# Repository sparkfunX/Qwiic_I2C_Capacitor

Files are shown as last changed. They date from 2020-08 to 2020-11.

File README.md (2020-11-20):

SparkFun Qwiic Digital Capacitor
=============================

SparkFun Qwiic Digital Capacitor - NCD2400M

[*SparkFun Qwiic Digital Capacitor NCD2400M (SPX- 17182)*](https://www.sparkfun.com/products/17182) 

Ever need to fine tune an oscillator circuit or RF filter? It can be tricky and repetitive switching out capacitors on a PCB. The Qwiic Digital Capacitor, complete with the NCD2400M IC, can be a great solution. Solder the nibs onto any 0603 or 0402 footprint, plug in a Qwiic cable and RedBoard, and change the capacitance in code.

Repository Contents
-------------------

* **/Documents** - Datasheet for the NCD2400M IC.
* **/Hardware** - Eagle design files (.brd, .sch).
* **/Production** - Production panel files (.brd).

Documentation
-------------
* **[Arduino Library](https://github.com/sparkfun/SparkFun_Qwiic_Digital_Capacitor_Arduino_Library)** - Arduino library for the SparkFun Qwiic Digital Capacitor - NCD2400M.

License Information
-------------------

This product is _**open source**_!

Please review the LICENSE.md file for license information.

If you have any questions or concerns regarding our licensing, please contact technical support on our [SparkFun Forum](https://www.sparkfun.com/viewforum.php?f=152).

Distributed as-is; no warranty is given.

- Your friends at SparkFun

_<COLLABORATION CREDIT>_

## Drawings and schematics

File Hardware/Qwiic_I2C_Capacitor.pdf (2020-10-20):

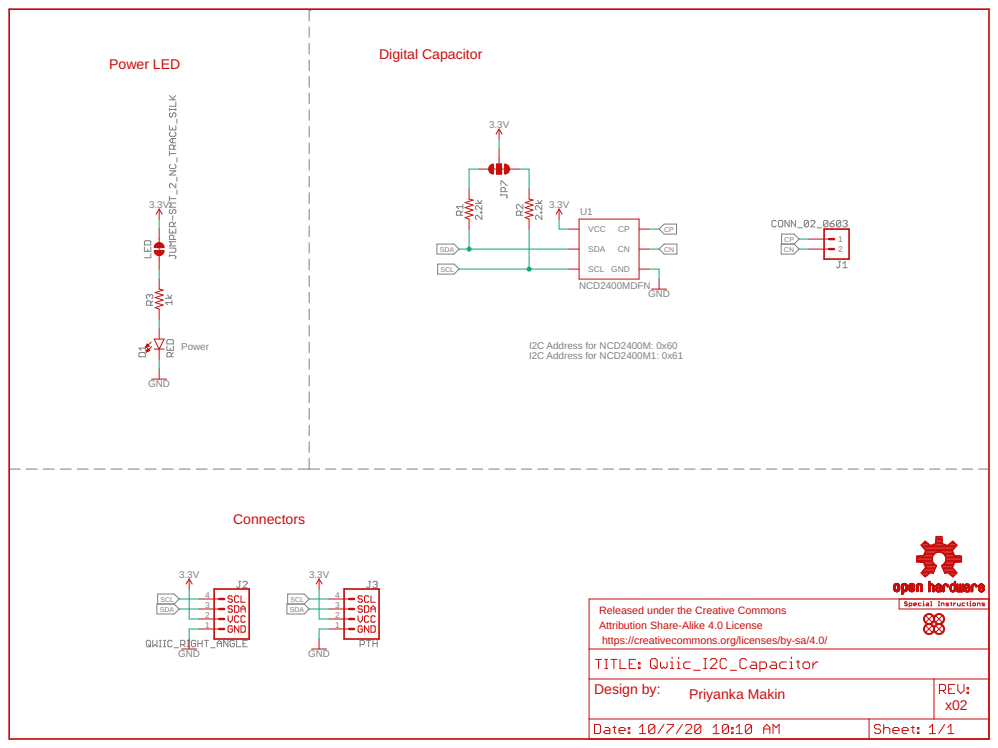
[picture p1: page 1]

Released under the Creative Commons Attribution Share-Alike 4.0 License

https://creativecommons.org/licenses/by-sa/4.0/

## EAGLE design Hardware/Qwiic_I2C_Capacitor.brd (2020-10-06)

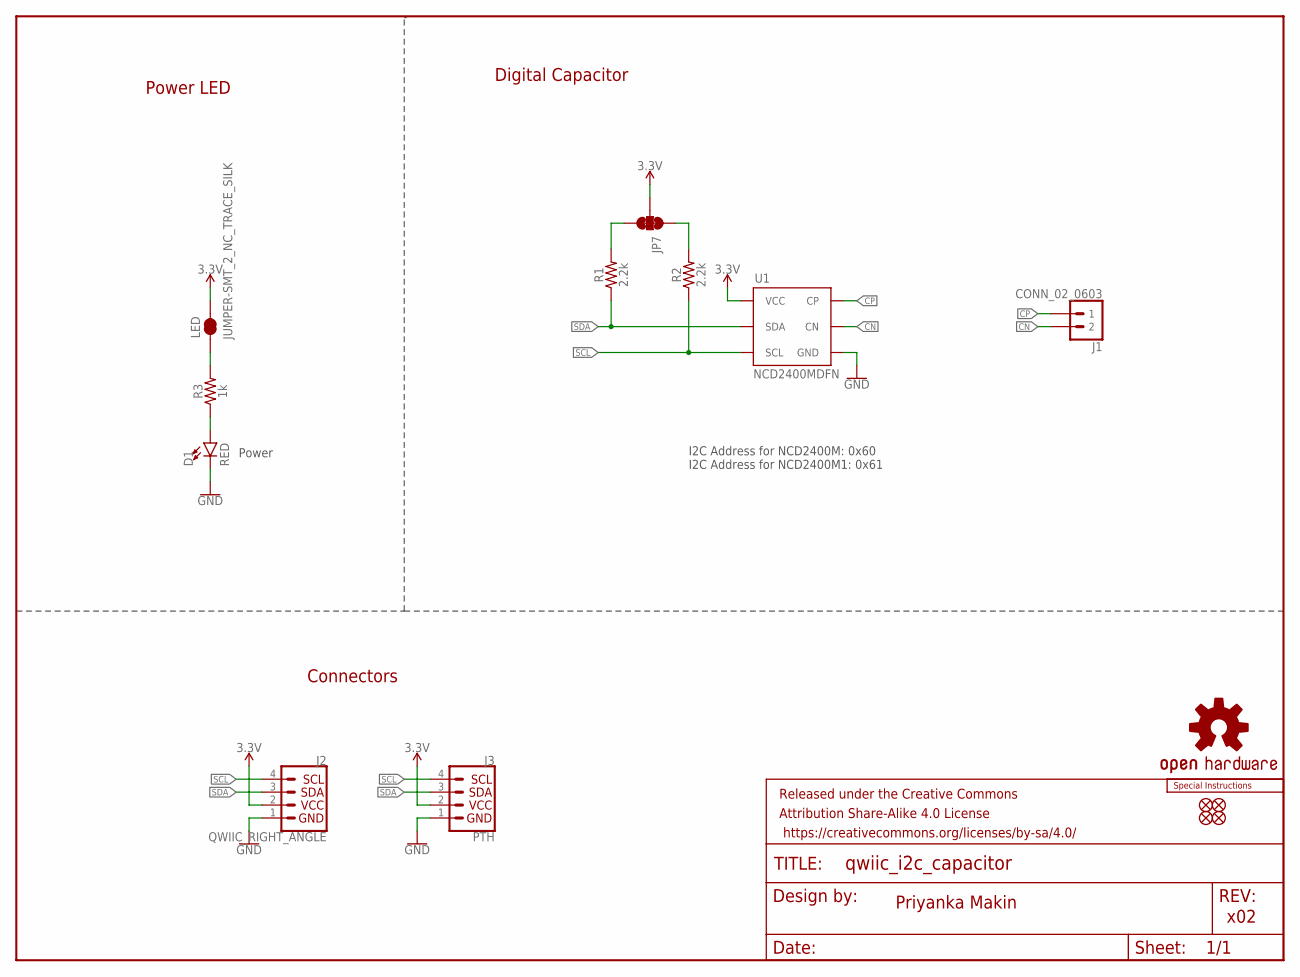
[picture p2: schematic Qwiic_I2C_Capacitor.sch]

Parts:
D1: RED; LED-0603
FRAME1: FRAME-LETTER; CREATIVE_COMMONS
J1: CONN_02_0603; 0603_CASTELLATED
J2: QWIIC_RIGHT_ANGLE; JST04_1MM_RA
J3: PTH; 1X04_NO_SILK
JP1, JP2, JP5, JP6: FIDUCIAL0.2MM; FIDUCIAL-0.2MM
JP7: JUMPER-SMT_3_2-NC_TRACE_SILK; SMT-JUMPER_3_2-NC_TRACE_SILK
LED: JUMPER-SMT_2_NC_TRACE_SILK; SMT-JUMPER_2_NC_TRACE_SILK
LOGO1: OSHW-LOGOMINI; OSHW-LOGO-MINI
LOGO2: SPECIAL_INSTRUCTIONS-ORDERING; ORDERING_INSTRUCTIONS
R1, R2: 2.2k; 0603
R3: 1k; 0603
U1: NCD2400MDFN; DFN6

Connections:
3.3V: J2.2, J3.2 (VCC), JP7.2, LED.2, U1.4 (VCC)
CN: J1.2, U1.3 (CN)
CP: J1.1, U1.2 (CP)
GND: D1.C, J2.1, J3.1 (GND), U1.5 (GND)
unnamed: JP7.3, R1.2
unnamed: JP7.1, R2.2
unnamed: D1.A, R3.1
unnamed: LED.1, R3.2
SCL: J2.4, J3.4 (SCL), R2.1, U1.6 (SCL)
SDA: J2.3, J3.3 (SDA), R1.1, U1.1 (SDA)

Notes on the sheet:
x02
Power
Connectors
Priyanka Makin
I2C Address for NCD2400M: 0x60 I2C Address for NCD2400M1: 0x61
Digital Capacitor
Power LED

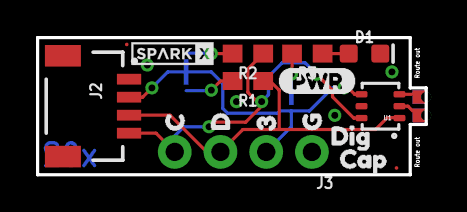
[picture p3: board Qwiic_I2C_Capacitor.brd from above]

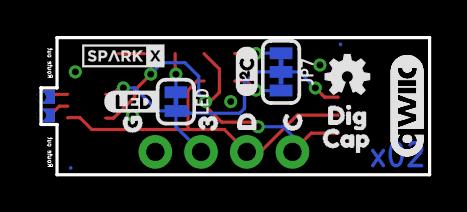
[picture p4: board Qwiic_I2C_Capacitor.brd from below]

Board: 2 copper layers, 21.6 x 7.6 mm, 36 parts (16 on the bottom side), 10 nets.

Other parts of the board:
U$1: PWR2
U$3, U$7: 32
U$4, U$8: C0
U$5, U$13: D1
U$6, U$14: G3
U$9: I_SUPER2_C-()-03
U$11, U$18: CAP1
U$12, U$16: SPARKX-TINY
U$15: LED0
U$20, U$21: QWIIC_COPYRIGHT_SMALL
U$22, U$23: DIG0

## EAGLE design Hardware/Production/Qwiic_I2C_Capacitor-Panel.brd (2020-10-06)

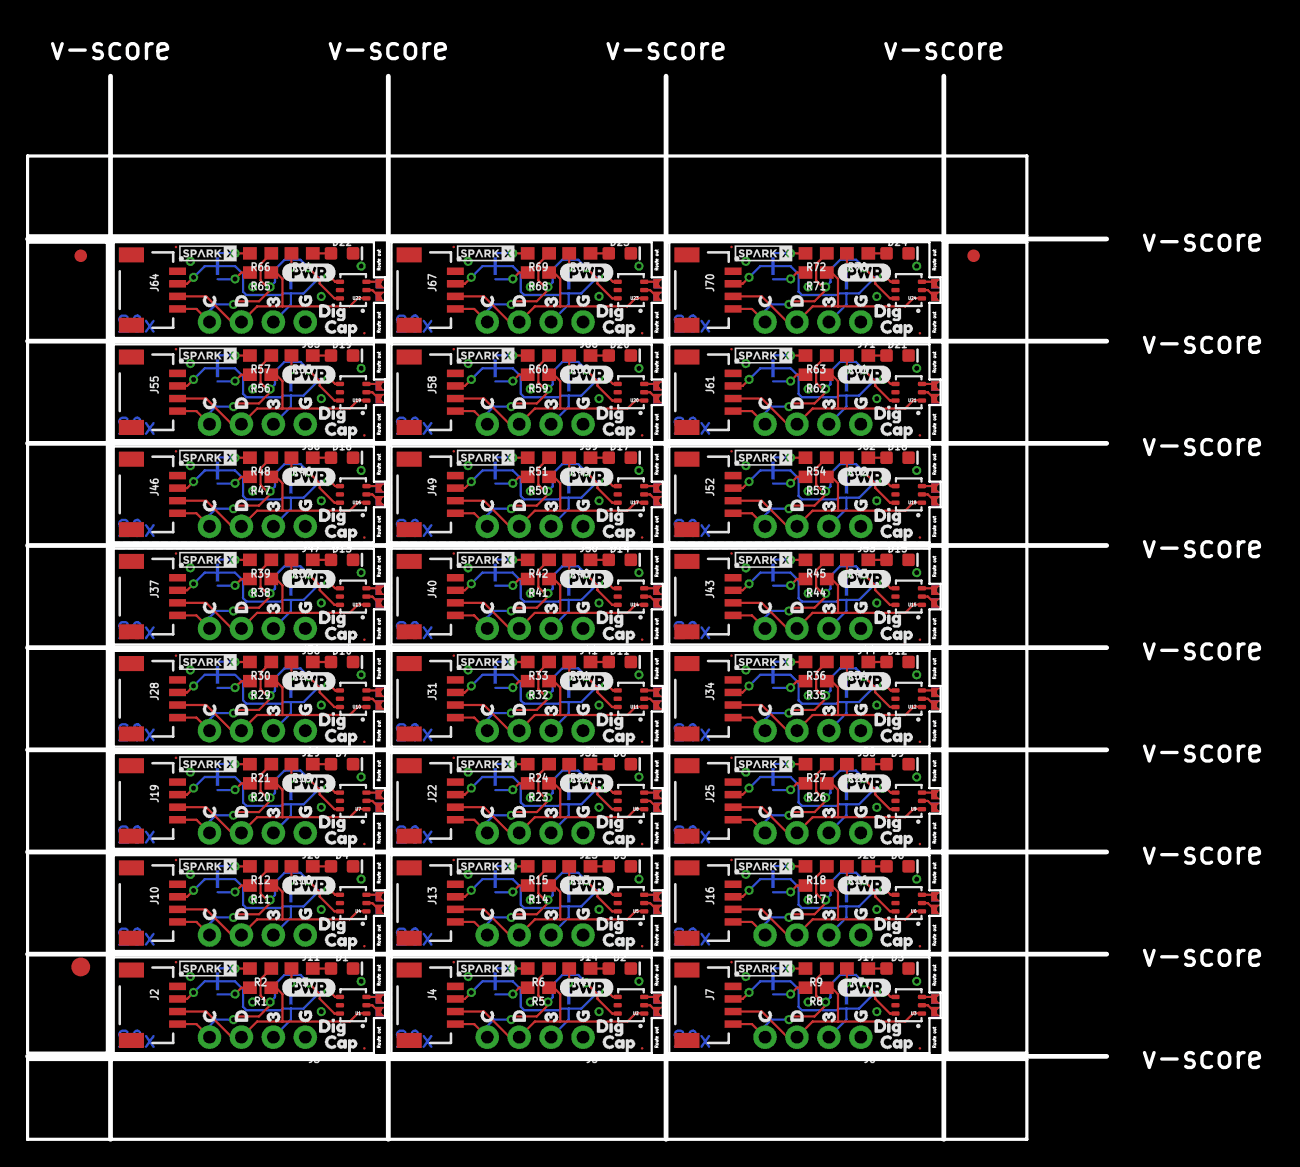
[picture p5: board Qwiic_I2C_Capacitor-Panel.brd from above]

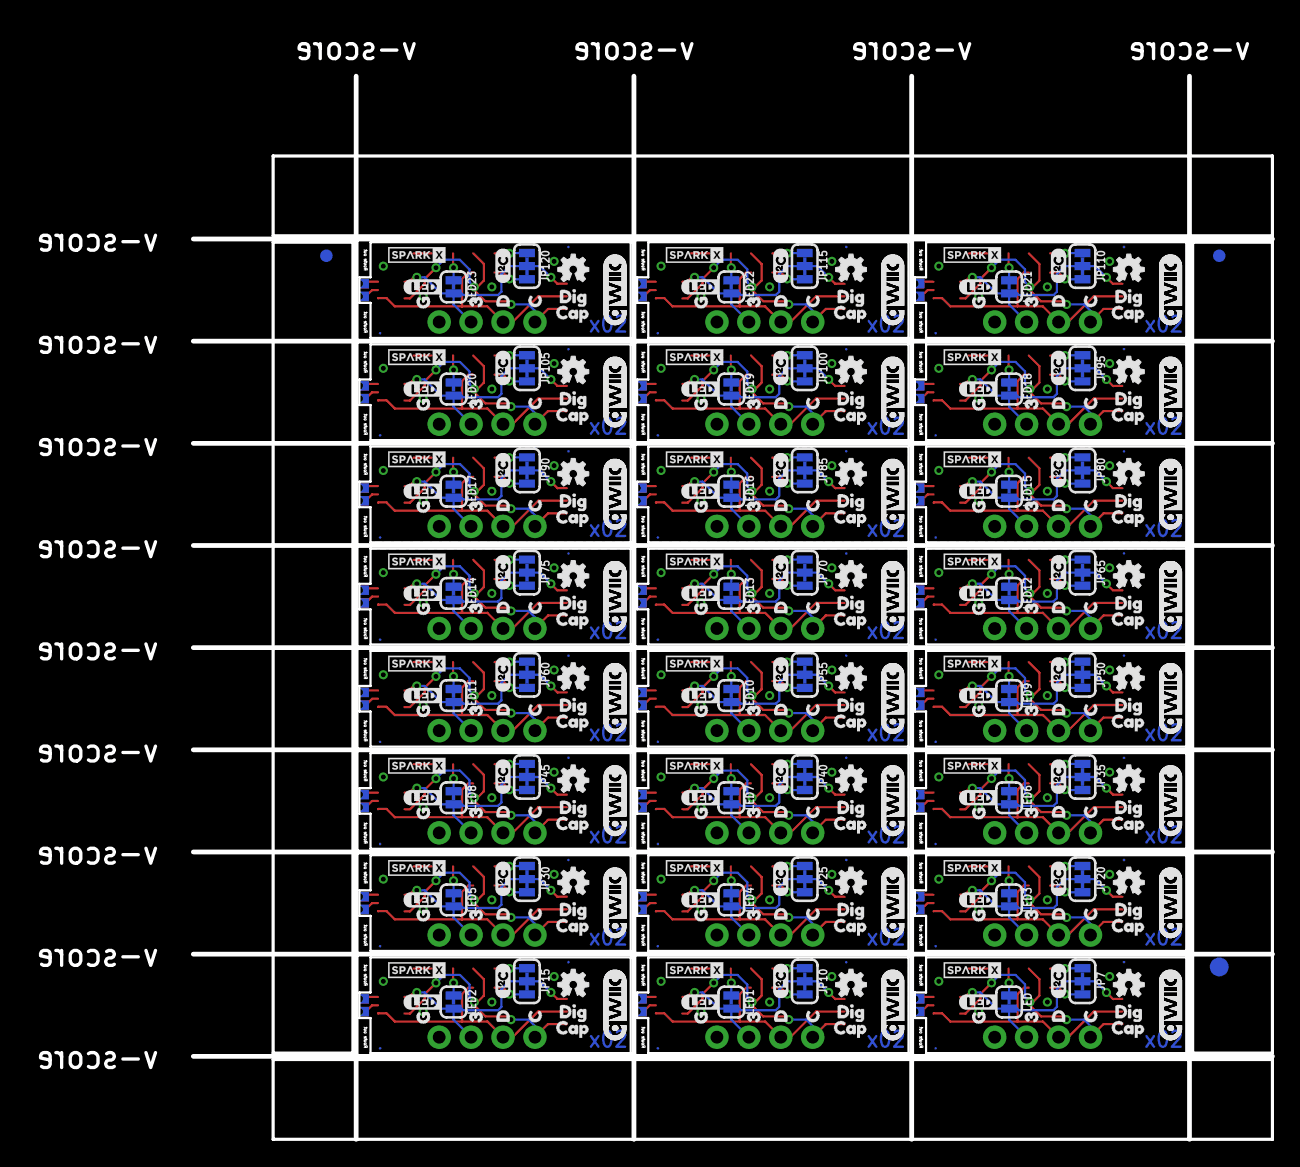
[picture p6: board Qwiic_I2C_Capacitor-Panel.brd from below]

Board: 2 copper layers, 85.9 x 84.6 mm, 822 parts (387 on the bottom side), 240 nets.

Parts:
D1, D2, D3, D4, D5, D6, D7, D8, D9, D10, D11, D12, D13, D14, D15, D16, D17, D18, D19, D20, D21, D22, D23, D24: RED; LED-0603
E$1, E$2, E$3, E$4: FIDUCIAL-1X2
E$5, E$6: FIDUCIAL-1.5X3
J1, J6, J9, J12, J15, J18, J21, J24, J27, J30, J33, J36, J39, J42, J45, J48, J51, J54, J57, J60, J63, J66, J69, J72: CONN_02_0603; 0603_CASTELLATED
J2, J4, J7, J10, J13, J16, J19, J22, J25, J28, J31, J34, J37, J40, J43, J46, J49, J52, J55, J58, J61, J64, J67, J70: QWIIC_RIGHT_ANGLE; JST04_1MM_RA
J3, J5, J8, J11, J14, J17, J20, J23, J26, J29, J32, J35, J38, J41, J44, J47, J50, J53, J56, J59, J62, J65, J68, J71: PTH; 1X04_NO_SILK
JP1, JP2, JP3, JP4, JP5, JP6, JP8, JP9, JP11, JP12, JP13, JP14, JP16, JP17, JP18, JP19, JP21, JP22, JP23, JP24, JP26, JP27, JP28, JP29, JP31, JP32, JP33, JP34, JP36, JP37, JP38, JP39, JP41, JP42, JP43, JP44, JP46, JP47, JP48, JP49, JP51, JP52, JP53, JP54, JP56, JP57, JP58, JP59, JP61, JP62, JP63, JP64, JP66, JP67, JP68, JP69, JP71, JP72, JP73, JP74, JP76, JP77, JP78, JP79, JP81, JP82, JP83, JP84, JP86, JP87, JP88, JP89, JP91, JP92, JP93, JP94, JP96, JP97, JP98, JP99, JP101, JP102, JP103, JP104, JP106, JP107, JP108, JP109, JP111, JP112, JP113, JP114, JP116, JP117, JP118, JP119: FIDUCIAL0.2MM; FIDUCIAL-0.2MM
JP7, JP10, JP15, JP20, JP25, JP30, JP35, JP40, JP45, JP50, JP55, JP60, JP65, JP70, JP75, JP80, JP85, JP90, JP95, JP100, JP105, JP110, JP115, JP120: JUMPER-SMT_3_2-NC_TRACE_SILK; SMT-JUMPER_3_2-NC_TRACE_SILK
LED, LED1, LED2, LED3, LED4, LED5, LED6, LED7, LED8, LED9, LED10, LED11, LED12, LED13, LED14, LED15, LED16, LED17, LED18, LED19, LED20, LED21, LED22, LED23: JUMPER-SMT_2_NC_TRACE_SILK; SMT-JUMPER_2_NC_TRACE_SILK
LOGO1, LOGO2, LOGO3, LOGO4, LOGO5, LOGO6, LOGO7, LOGO8, LOGO9, LOGO10, LOGO11, LOGO12, LOGO13, LOGO14, LOGO15, LOGO16, LOGO17, LOGO18, LOGO19, LOGO20, LOGO21, LOGO22, LOGO23, LOGO24: OSHW-LOGOMINI; OSHW-LOGO-MINI
R1, R2, R5, R6, R8, R9, R11, R12, R14, R15, R17, R18, R20, R21, R23, R24, R26, R27, R29, R30, R32, R33, R35, R36, R38, R39, R41, R42, R44, R45, R47, R48, R50, R51, R53, R54, R56, R57, R59, R60, R62, R63, R65, R66, R68, R69, R71, R72: 2.2k; 0603
R3, R4, R7, R10, R13, R16, R19, R22, R25, R28, R31, R34, R37, R40, R43, R46, R49, R52, R55, R58, R61, R64, R67, R70: 1k; 0603
U1, U2, U3, U4, U5, U6, U7, U8, U9, U10, U11, U12, U13, U14, U15, U16, U17, U18, U19, U20, U21, U22, U23, U24: NCD2400MDFN; DFN6
U$1, U$38, U$57, U$76, U$95, U$114, U$133, U$152, U$171, U$190, U$209, U$228, U$247, U$266, U$285, U$304, U$323, U$342, U$361, U$380, U$399, U$418, U$437, U$456: PWR2
U$2, U$9, U$39, U$58, U$77, U$96, U$115, U$134, U$153, U$172, U$191, U$210, U$229, U$248, U$267, U$286, U$305, U$324, U$343, U$362, U$381, U$400, U$419, U$438: I_SUPER2_C-()-03
U$3, U$7, U$10, U$25, U$40, U$44, U$59, U$63, U$78, U$82, U$97, U$101, U$116, U$120, U$135, U$139, U$154, U$158, U$173, U$177, U$192, U$196, U$211, U$215, U$230, U$234, U$249, U$253, U$268, U$272, U$287, U$291, U$306, U$310, U$325, U$329, U$344, U$348, U$363, U$367, U$382, U$386, U$401, U$405, U$420, U$424, U$439, U$443: 32
U$4, U$8, U$17, U$26, U$41, U$45, U$60, U$64, U$79, U$83, U$98, U$102, U$117, U$121, U$136, U$140, U$155, U$159, U$174, U$178, U$193, U$197, U$212, U$216, U$231, U$235, U$250, U$254, U$269, U$273, U$288, U$292, U$307, U$311, U$326, U$330, U$345, U$349, U$364, U$368, U$383, U$387, U$402, U$406, U$421, U$425, U$440, U$444: C0
U$5, U$13, U$19, U$27, U$42, U$46, U$61, U$65, U$80, U$84, U$99, U$103, U$118, U$122, U$137, U$141, U$156, U$160, U$175, U$179, U$194, U$198, U$213, U$217, U$232, U$236, U$251, U$255, U$270, U$274, U$289, U$293, U$308, U$312, U$327, U$331, U$346, U$350, U$365, U$369, U$384, U$388, U$403, U$407, U$422, U$426, U$441, U$445: D1
U$6, U$14, U$24, U$28, U$43, U$47, U$62, U$66, U$81, U$85, U$100, U$104, U$119, U$123, U$138, U$142, U$157, U$161, U$176, U$180, U$195, U$199, U$214, U$218, U$233, U$237, U$252, U$256, U$271, U$275, U$290, U$294, U$309, U$313, U$328, U$332, U$347, U$351, U$366, U$370, U$385, U$389, U$404, U$408, U$423, U$427, U$442, U$446: G3
U$11, U$18, U$34, U$35, U$53, U$54, U$72, U$73, U$91, U$92, U$110, U$111, U$129, U$130, U$148, U$149, U$167, U$168, U$186, U$187, U$205, U$206, U$224, U$225, U$243, U$244, U$262, U$263, U$281, U$282, U$300, U$301, U$319, U$320, U$338, U$339, U$357, U$358, U$376, U$377, U$395, U$396, U$414, U$415, U$433, U$434, U$452, U$453: CAP1
U$12, U$16, U$30, U$31, U$49, U$50, U$68, U$69, U$87, U$88, U$106, U$107, U$125, U$126, U$144, U$145, U$163, U$164, U$182, U$183, U$201, U$202, U$220, U$221, U$239, U$240, U$258, U$259, U$277, U$278, U$296, U$297, U$315, U$316, U$334, U$335, U$353, U$354, U$372, U$373, U$391, U$392, U$410, U$411, U$429, U$430, U$448, U$449: SPARKX-TINY
U$15, U$29, U$48, U$67, U$86, U$105, U$124, U$143, U$162, U$181, U$200, U$219, U$238, U$257, U$276, U$295, U$314, U$333, U$352, U$371, U$390, U$409, U$428, U$447: LED0
U$20, U$21, U$32, U$33, U$51, U$52, U$70, U$71, U$89, U$90, U$108, U$109, U$127, U$128, U$146, U$147, U$165, U$166, U$184, U$185, U$203, U$204, U$222, U$223, U$241, U$242, U$260, U$261, U$279, U$280, U$298, U$299, U$317, U$318, U$336, U$337, U$355, U$356, U$374, U$375, U$393, U$394, U$412, U$413, U$431, U$432, U$450, U$451: QWIIC_COPYRIGHT_SMALL
U$22, U$23, U$36, U$37, U$55, U$56, U$74, U$75, U$93, U$94, U$112, U$113, U$131, U$132, U$150, U$151, U$169, U$170, U$188, U$189, U$207, U$208, U$226, U$227, U$245, U$246, U$264, U$265, U$283, U$284, U$302, U$303, U$321, U$322, U$340, U$341, U$359, U$360, U$378, U$379, U$397, U$398, U$416, U$417, U$435, U$436, U$454, U$455: DIG0

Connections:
3.3V: J2.2, J3.2, JP7.2, LED.2, U1.4
3.3V1: J4.2, J5.2, JP10.2, LED1.2, U2.4
3.3V2: J7.2, J8.2, JP15.2, LED2.2, U3.4
3.3V3: J10.2, J11.2, JP20.2, LED3.2, U4.4
3.3V4: J13.2, J14.2, JP25.2, LED4.2, U5.4
3.3V5: J16.2, J17.2, JP30.2, LED5.2, U6.4
3.3V6: J19.2, J20.2, JP35.2, LED6.2, U7.4
3.3V7: J22.2, J23.2, JP40.2, LED7.2, U8.4
3.3V8: J25.2, J26.2, JP45.2, LED8.2, U9.4
3.3V9: J28.2, J29.2, JP50.2, LED9.2, U10.4
3.3V10: J31.2, J32.2, JP55.2, LED10.2, U11.4
3.3V11: J34.2, J35.2, JP60.2, LED11.2, U12.4
3.3V12: J37.2, J38.2, JP65.2, LED12.2, U13.4
3.3V13: J40.2, J41.2, JP70.2, LED13.2, U14.4
3.3V14: J43.2, J44.2, JP75.2, LED14.2, U15.4
3.3V15: J46.2, J47.2, JP80.2, LED15.2, U16.4
3.3V16: J49.2, J50.2, JP85.2, LED16.2, U17.4
3.3V17: J52.2, J53.2, JP90.2, LED17.2, U18.4
3.3V18: J55.2, J56.2, JP95.2, LED18.2, U19.4
3.3V19: J58.2, J59.2, JP100.2, LED19.2, U20.4
3.3V20: J61.2, J62.2, JP105.2, LED20.2, U21.4
3.3V21: J64.2, J65.2, JP110.2, LED21.2, U22.4
3.3V22: J67.2, J68.2, JP115.2, LED22.2, U23.4
3.3V23: J70.2, J71.2, JP120.2, LED23.2, U24.4
CN: J1.2, U1.3
CN1: J6.2, U2.3
CN2: J9.2, U3.3
CN3: J12.2, U4.3
CN4: J15.2, U5.3
CN5: J18.2, U6.3
CN6: J21.2, U7.3
CN7: J24.2, U8.3
CN8: J27.2, U9.3
CN9: J30.2, U10.3
CN10: J33.2, U11.3
CN11: J36.2, U12.3
CN12: J39.2, U13.3
CN13: J42.2, U14.3
CN14: J45.2, U15.3
CN15: J48.2, U16.3
CN16: J51.2, U17.3
CN17: J54.2, U18.3
CN18: J57.2, U19.3
CN19: J60.2, U20.3
CN20: J63.2, U21.3
CN21: J66.2, U22.3
CN22: J69.2, U23.3
CN23: J72.2, U24.3
CP: J1.1, U1.2
CP1: J6.1, U2.2
CP2: J9.1, U3.2
CP3: J12.1, U4.2
CP4: J15.1, U5.2
CP5: J18.1, U6.2
CP6: J21.1, U7.2
CP7: J24.1, U8.2
CP8: J27.1, U9.2
CP9: J30.1, U10.2
CP10: J33.1, U11.2
CP11: J36.1, U12.2
CP12: J39.1, U13.2
CP13: J42.1, U14.2
CP14: J45.1, U15.2
CP15: J48.1, U16.2
CP16: J51.1, U17.2
CP17: J54.1, U18.2
CP18: J57.1, U19.2
CP19: J60.1, U20.2
CP20: J63.1, U21.2
CP21: J66.1, U22.2
CP22: J69.1, U23.2
CP23: J72.1, U24.2
GND: D1.C, J2.1, J3.1, U1.5
GND1: D2.C, J4.1, J5.1, U2.5
GND2: D3.C, J7.1, J8.1, U3.5
GND3: D4.C, J10.1, J11.1, U4.5
GND4: D5.C, J13.1, J14.1, U5.5
GND5: D6.C, J16.1, J17.1, U6.5
GND6: D7.C, J19.1, J20.1, U7.5
GND7: D8.C, J22.1, J23.1, U8.5
GND8: D9.C, J25.1, J26.1, U9.5
GND9: D10.C, J28.1, J29.1, U10.5
GND10: D11.C, J31.1, J32.1, U11.5
GND11: D12.C, J34.1, J35.1, U12.5
GND12: D13.C, J37.1, J38.1, U13.5
GND13: D14.C, J40.1, J41.1, U14.5
GND14: D15.C, J43.1, J44.1, U15.5
GND15: D16.C, J46.1, J47.1, U16.5
GND16: D17.C, J49.1, J50.1, U17.5
GND17: D18.C, J52.1, J53.1, U18.5
GND18: D19.C, J55.1, J56.1, U19.5
GND19: D20.C, J58.1, J59.1, U20.5
GND20: D21.C, J61.1, J62.1, U21.5
GND21: D22.C, J64.1, J65.1, U22.5
GND22: D23.C, J67.1, J68.1, U23.5
GND23: D24.C, J70.1, J71.1, U24.5
unnamed: JP7.3, R1.2
unnamed: JP7.1, R2.2
unnamed: D1.A, R3.1
unnamed: LED.1, R3.2
unnamed: D2.A, R4.1
unnamed: JP10.3, R5.2
unnamed: JP10.1, R6.2
unnamed: LED1.1, R4.2
unnamed: D3.A, R7.1
unnamed: JP15.3, R8.2
unnamed: JP15.1, R9.2
unnamed: LED2.1, R7.2
unnamed: D4.A, R10.1
unnamed: JP20.3, R11.2
unnamed: JP20.1, R12.2
unnamed: LED3.1, R10.2
unnamed: D5.A, R13.1
unnamed: JP25.3, R14.2
unnamed: JP25.1, R15.2
unnamed: LED4.1, R13.2
unnamed: D6.A, R16.1
unnamed: JP30.3, R17.2
unnamed: JP30.1, R18.2
unnamed: LED5.1, R16.2
unnamed: D7.A, R19.1
unnamed: JP35.3, R20.2
unnamed: JP35.1, R21.2
unnamed: LED6.1, R19.2
unnamed: D8.A, R22.1
unnamed: JP40.3, R23.2
unnamed: JP40.1, R24.2
unnamed: LED7.1, R22.2
unnamed: D9.A, R25.1
unnamed: JP45.3, R26.2
unnamed: JP45.1, R27.2
unnamed: LED8.1, R25.2
unnamed: D10.A, R28.1
unnamed: JP50.3, R29.2
unnamed: JP50.1, R30.2
unnamed: LED9.1, R28.2
unnamed: D11.A, R31.1
unnamed: JP55.3, R32.2
unnamed: JP55.1, R33.2
unnamed: LED10.1, R31.2
unnamed: D12.A, R34.1
unnamed: JP60.3, R35.2
unnamed: JP60.1, R36.2
unnamed: LED11.1, R34.2
unnamed: D13.A, R37.1
unnamed: JP65.3, R38.2
unnamed: JP65.1, R39.2
unnamed: LED12.1, R37.2
unnamed: D14.A, R40.1
unnamed: JP70.3, R41.2
unnamed: JP70.1, R42.2
unnamed: LED13.1, R40.2
unnamed: D15.A, R43.1
unnamed: JP75.3, R44.2
unnamed: JP75.1, R45.2
unnamed: LED14.1, R43.2
unnamed: D16.A, R46.1
unnamed: JP80.3, R47.2
unnamed: JP80.1, R48.2
unnamed: LED15.1, R46.2
unnamed: D17.A, R49.1
unnamed: JP85.3, R50.2
unnamed: JP85.1, R51.2
unnamed: LED16.1, R49.2
unnamed: D18.A, R52.1
unnamed: JP90.3, R53.2
unnamed: JP90.1, R54.2
unnamed: LED17.1, R52.2
unnamed: D19.A, R55.1
unnamed: JP95.3, R56.2
unnamed: JP95.1, R57.2
unnamed: LED18.1, R55.2
unnamed: D20.A, R58.1
unnamed: JP100.3, R59.2
unnamed: JP100.1, R60.2
unnamed: LED19.1, R58.2
unnamed: D21.A, R61.1
unnamed: JP105.3, R62.2
unnamed: JP105.1, R63.2
unnamed: LED20.1, R61.2
unnamed: D22.A, R64.1
unnamed: JP110.3, R65.2
unnamed: JP110.1, R66.2
unnamed: LED21.1, R64.2
unnamed: D23.A, R67.1
unnamed: JP115.3, R68.2
unnamed: JP115.1, R69.2
unnamed: LED22.1, R67.2
unnamed: D24.A, R70.1
unnamed: JP120.3, R71.2
unnamed: JP120.1, R72.2
unnamed: LED23.1, R70.2
SCL: J2.4, J3.4, R2.1, U1.6
SCL1: J4.4, J5.4, R6.1, U2.6
SCL2: J7.4, J8.4, R9.1, U3.6
SCL3: J10.4, J11.4, R12.1, U4.6
SCL4: J13.4, J14.4, R15.1, U5.6
SCL5: J16.4, J17.4, R18.1, U6.6
SCL6: J19.4, J20.4, R21.1, U7.6
SCL7: J22.4, J23.4, R24.1, U8.6
SCL8: J25.4, J26.4, R27.1, U9.6
SCL9: J28.4, J29.4, R30.1, U10.6
SCL10: J31.4, J32.4, R33.1, U11.6
SCL11: J34.4, J35.4, R36.1, U12.6
SCL12: J37.4, J38.4, R39.1, U13.6
SCL13: J40.4, J41.4, R42.1, U14.6
SCL14: J43.4, J44.4, R45.1, U15.6
SCL15: J46.4, J47.4, R48.1, U16.6
SCL16: J49.4, J50.4, R51.1, U17.6
SCL17: J52.4, J53.4, R54.1, U18.6
SCL18: J55.4, J56.4, R57.1, U19.6
SCL19: J58.4, J59.4, R60.1, U20.6
SCL20: J61.4, J62.4, R63.1, U21.6
SCL21: J64.4, J65.4, R66.1, U22.6
SCL22: J67.4, J68.4, R69.1, U23.6
SCL23: J70.4, J71.4, R72.1, U24.6
SDA: J2.3, J3.3, R1.1, U1.1
SDA1: J4.3, J5.3, R5.1, U2.1
SDA2: J7.3, J8.3, R8.1, U3.1
SDA3: J10.3, J11.3, R11.1, U4.1
SDA4: J13.3, J14.3, R14.1, U5.1
SDA5: J16.3, J17.3, R17.1, U6.1
SDA6: J19.3, J20.3, R20.1, U7.1
SDA7: J22.3, J23.3, R23.1, U8.1
SDA8: J25.3, J26.3, R26.1, U9.1
SDA9: J28.3, J29.3, R29.1, U10.1
SDA10: J31.3, J32.3, R32.1, U11.1
SDA11: J34.3, J35.3, R35.1, U12.1
SDA12: J37.3, J38.3, R38.1, U13.1
SDA13: J40.3, J41.3, R41.1, U14.1
SDA14: J43.3, J44.3, R44.1, U15.1
SDA15: J46.3, J47.3, R47.1, U16.1
SDA16: J49.3, J50.3, R50.1, U17.1
SDA17: J52.3, J53.3, R53.1, U18.1
SDA18: J55.3, J56.3, R56.1, U19.1
SDA19: J58.3, J59.3, R59.1, U20.1
SDA20: J61.3, J62.3, R62.1, U21.1
SDA21: J64.3, J65.3, R65.1, U22.1
SDA22: J67.3, J68.3, R68.1, U23.1
SDA23: J70.3, J71.3, R71.1, U24.1

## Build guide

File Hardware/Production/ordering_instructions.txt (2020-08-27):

panel size, 80x72mm
PCB thickness, 0.8mm
number of layers, 2
soldermask color, Black
silkscreen color, White
oz copper, 1oz
finish, HASL lead free
stencils, top
pcs per panel, 24
min trace width, 0.1778mm / 0.0070in
min drill size, 0.3810mm / 0.0150in

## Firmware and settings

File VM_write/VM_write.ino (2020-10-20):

#include "Wire.h"

const int address = 0x60;

void setup() {
  Wire.begin();
  Serial.begin(115200);

  Serial.println("Write 0x5 to volatilte memory:");
  Wire.beginTransmission(address);
  Wire.write(0x00);
  Wire.write(0x6A);
  Wire.endTransmission();
  
  //This is the read function
  Wire.requestFrom(address, 4);
  while(Wire.available()) {
    uint8_t temp = Wire.read();
    Serial.print("0x");
    Serial.println(temp, HEX);
  }

//  Serial.println("Write 0x7 to volatile memory:");
//  Wire.beginTransmission(address);
//  Wire.write(0x00);
//  Wire.write(0x07);
//  Wire.endTransmission();
//
//  //This is the read function
//  Wire.requestFrom(address, 4);
//  while(Wire.available()) {
//    uint8_t temp = Wire.read();
//    Serial.print("0x");
//    Serial.println(temp, HEX);
//  }
//
//  Serial.println("Write 0x1F9 to volatile memory:");
//  Wire.beginTransmission(address);
//  Wire.write(0x01);
//  Wire.write(0xF9);
//  Wire.endTransmission();
// 
//  //This is the read function
//  Wire.requestFrom(address, 4);
//  while(Wire.available()) {
//    uint8_t temp = Wire.read();
//    Serial.print("0x");
//    Serial.println(temp, HEX);
//  }
}

void loop() {
  // put your main code here, to run repeatedly:

}

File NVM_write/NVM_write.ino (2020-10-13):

#include "Wire.h"

const int address = 0x60;

void setup() {
  // put your setup code here, to run once:
  Wire.begin();
  Serial.begin(115200);

  Serial.println("Write 0x7D to NVM");

  
  //Clear NV address 0x0
  Wire.beginTransmission(address);
  //Config 1
  Wire.write(0x80);
  //Config 0
  Wire.write(0xF0);
  //Wait
  Wire.write(0xFF);
  Wire.endTransmission();

  //Write 0xD to NV address 0x0
  Wire.beginTransmission(address);
  //Config 1
  Wire.write(0x80);
  //Config 0
  Wire.write(0xFD);
  //Wait
  Wire.write(0xFF);
  Wire.endTransmission();

  //Clear NV address 0x1
  Wire.beginTransmission(address);
  //Config 1
  Wire.write(0xA0);
  //Config 0
  Wire.write(0xF0);
  //Wait
  Wire.write(0xFF);
  Wire.endTransmission();

  //Write 0x7 to NV address 0x1
  Wire.beginTransmission(address);
  //Config 1
  Wire.write(0xA0);
  //Config 0
  Wire.write(0xF7);
  //Wait
  Wire.write(0xFF);
  Wire.endTransmission();

  //Clear NV address 0x2
  Wire.beginTransmission(address);
  //Config 1
  Wire.write(0xC0);
  //Config 0
  Wire.write(0xF0);
  //Wait
  Wire.write(0xFF);
  Wire.endTransmission();


  
  //This is the read function
  Wire.requestFrom(address, 4);
  while(Wire.available()) {
    uint8_t temp = Wire.read();
    Serial.print("0x");
    Serial.println(temp, HEX);
  }
  
    //Set NVM mode -- I think this works
  Wire.beginTransmission(address);
  Wire.write(0x90);
  Wire.write(0xFF);
  Wire.endTransmission();
}

void loop() {
  // put your main code here, to run repeatedly:

}

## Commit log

2020-08-24 Added NCD2400M to schematic
    [Qwiic AHT20 Breakout.brd, Qwiic AHT20 Breakout.sch]
2020-08-24 Renamed eagle files
    [Qwiic_I2C_Capacitor.brd, Qwiic_I2C_Capacitor.sch]
2020-08-27 Initial layout
    [Qwiic_I2C_Capacitor.brd, Qwiic_I2C_Capacitor.sch]
2020-08-27 Changes from board review
    [Qwiic_I2C_Capacitor.brd, Qwiic_I2C_Capacitor.sch]
2020-08-27 Panelizer/cam output
    [Qwiic_I2C_Capacitor-Panel.GBL, Qwiic_I2C_Capacitor-Panel.GBO, Qwiic_I2C_Capacitor-Panel.GBP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]
2020-10-06 Rev x02
    Re-routed SDA and SCL. They were backwards in the previous version x01
    [Qwiic_I2C_Capacitor-Panel.brd, Qwiic_I2C_Capacitor.brd, Qwiic_I2C_Capacitor.sch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]

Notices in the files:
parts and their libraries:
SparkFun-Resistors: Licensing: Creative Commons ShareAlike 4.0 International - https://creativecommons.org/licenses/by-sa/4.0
